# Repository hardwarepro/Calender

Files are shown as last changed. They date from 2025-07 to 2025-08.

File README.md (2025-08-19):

# Calender
This is a custom-built calender PCB that allows me to upload my school schedule (or just counting down how many days of school I have left!) via WIFI (on an esp32) to an e-ink display and use it in my locker off a AA battery. When it's at home, it will be able to act as a music player or still a calender, allowing me to plug it in via usb-c or just by using wifi and display live music status.  

## Photos






## BOM

| Name | Part # | JLCPCB Part # | Qty | Total Price |
| :--- | :--- | :--- | :--- | :--- |
| 10uF | CL10A106KP8NNNC | C19702 | 20 | 0.112 |
| 4.7uF | CL10A475KO8NNNC | C19666 | 20 | 0.202 |
| 1uF | CL10A105KB8NNNC | C15849 | 20 | 0.094 |
| 100nF | CC0603KRX7R9BB104 | C14663 | 22 | 0.0506 |
| Conn_01x09 | ZX-PZ1.0-1-9PZZ | C37328859 | 2 | 0.2856 |
| USB_C_Receptacle_USB2.0_16P | GT-USB-7010ASV | C2988369 | 2 | 0.1572 |
| Power | DB128L-5.08-2P-GN-S | C395868 | 2 | 0.3622 |
| 5.1k | 0603WAF5101T5E | C23186 | 20 | 0.02 |
| 2k | 0603WAF2001T5E | C22975 | 20 | 0.02 |
| 10k | 0603WAF1002T5E | C25804 | 26 | 0.0234 |
| 100kΩ | 0603WAF1003T5E | C25803 | 20 | 0.02 |
| RotaryEncoder_Switch | EC11E18244AU | C202365 | 2 | 3.825 |
| SW_Push | BTSA-N-P-13 | C2693637 | 0 | 0 |
| ATSAMD21G18A-A | ATSAMD21G18A-AU | C78624 | 2 | 6.249 |
| MCP73871 | MCP73871T-2CCI/ML | C511310 | 2 | 7.482 |
| ESP-WROOM-02 | ESP-WROOM-02D-N4 | C529584 | 2 | 3.75 |
| AMS1117-3.3V | AMS1117-3.3V |  | 2 | 1.25 |
| PCB | | | $76.80 after tax + shipping ||

---

## Other Items

| Item | Details/Source | Qty | Price |
| :--- | :--- | :--- | :--- |
| 0.91 OLED | 0.91 OLED | 1 | $1.15 since mine just broke :( |
| E-Ink Display | [From Waveshare](https://www.waveshare.com/3.7inch-e-paper-hat-plus-g.htm?sku=31061) | 2 | $48.98 after tax + shipping |

---

### **TOTAL: $126.93 USD without customs**

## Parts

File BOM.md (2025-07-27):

| Name | Part # | JLCPCB Part # | Qty | Total Price |
| :--- | :--- | :--- | :--- | :--- |
| 10uF | CL10A106KP8NNNC | C19702 | 20 | 0.112 |
| 4.7uF | CL10A475KO8NNNC | C19666 | 20 | 0.202 |
| 1uF | CL10A105KB8NNNC | C15849 | 20 | 0.094 |
| 100nF | CC0603KRX7R9BB104 | C14663 | 22 | 0.0506 |
| Conn_01x09 | ZX-PZ1.0-1-9PZZ | C37328859 | 2 | 0.2856 |
| USB_C_Receptacle_USB2.0_16P | GT-USB-7010ASV | C2988369 | 2 | 0.1572 |
| Power | DB128L-5.08-2P-GN-S | C395868 | 2 | 0.3622 |
| 5.1k | 0603WAF5101T5E | C23186 | 20 | 0.02 |
| 2k | 0603WAF2001T5E | C22975 | 20 | 0.02 |
| 10k | 0603WAF1002T5E | C25804 | 26 | 0.0234 |
| 100kΩ | 0603WAF1003T5E | C25803 | 20 | 0.02 |
| RotaryEncoder_Switch | EC11E18244AU | C202365 | 2 | 3.825 |
| SW_Push | BTSA-N-P-13 | C2693637 | 0 | 0 |
| ATSAMD21G18A-A | ATSAMD21G18A-AU | C78624 | 2 | 6.249 |
| MCP73871 | MCP73871T-2CCI/ML | C511310 | 2 | 7.482 |
| ESP-WROOM-02 | ESP-WROOM-02D-N4 | C529584 | 2 | 3.75 |
| PCB | | | $71.70 after tax + shipping |

---

## Other Items

| Item | Details/Source | Qty | Price |
| :--- | :--- | :--- | :--- |
| AMS1117-3.3V (So I don't need to do 2 layer assembly. I will just hand-solder this myself)| From Digikey | 1 | $6.96 after tax + shipping |
| E-Ink Display | [From Waveshare](https://www.waveshare.com/3.7inch-e-paper-hat-plus-g.htm?sku=31061) | 1 | $26.99 after tax + $5 shipping |

---

### **TOTAL: $110 USD without customs**

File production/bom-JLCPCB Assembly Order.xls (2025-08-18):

JLCPCB BOM Tool - BOM Matching
BOM name：bom-JLCPCB Assembly Order.xlsx |  |  | Download Time：2025-08-19 04:42:18 |  |  |  | * Our matching results are updated in real-time, but stock and prices may change. If it's been over 24 hours, please re-match before placing your order.
PCB Assembled Qty：5 |  |  | Est. Total Price：26.9299
Your BOM |  |  |  |  | Matched Parts |  |  |  |  |  |  | Order Information
Top Designator | Bottom Designator | Comment | Footprint | JLCPCB Part # | Matches | Part # | Manufacturer | Footprint | Description | Category | Warning | JLCPCB Part # | Product link | Lib Type | Qty | Source | Total Price ($)
C1,C2 |  | 10uF | 0603 |  | Select by System | CL10A106KP8NNNC | Samsung Electro-Mechanics | 0603 | 10V 10uF X5R ±10% 0603 Multilayer Ceramic Capacitors MLCC - SMD/SMT ROHS | Multilayer Ceramic Capacitors MLCC - SMD/SMT |  | C19702 | https://jlcpcb.com/partdetail/20411-CL10A106KP8NNNC/C19702 | Basic | 4 | 4 JLCPCB | 0.0224
C3,C4 |  | 4.7uF | 0603 |  | Select by System | CL10A475KO8NNNC | Samsung Electro-Mechanics | 0603 | 16V 4.7uF X5R ±10% 0603 Multilayer Ceramic Capacitors MLCC - SMD/SMT ROHS | Multilayer Ceramic Capacitors MLCC - SMD/SMT |  | C19666 | https://jlcpcb.com/partdetail/20375-CL10A475KO8NNNC/C19666 | Basic | 4 | 4 JLCPCB | 0.0404
C5 |  | 1uF | 0603 |  | Select by System | CL10A105KB8NNNC | Samsung Electro-Mechanics | 0603 | 1uF 50V X5R ±10% 0603 Multilayer Ceramic Capacitors MLCC - SMD/SMT ROHS | Multilayer Ceramic Capacitors MLCC - SMD/SMT |  | C15849 | https://jlcpcb.com/partdetail/16531-CL10A105KB8NNNC/C15849 | Basic | 2 | 2 JLCPCB | 0.0094
C10,C11,C12,C6,C7,C8,C9 |  | 100nF | 0603 |  | Select by System | CC0603KRX7R9BB104 | YAGEO | 0603 | 100nF 50V X7R ±10% 0603 Multilayer Ceramic Capacitors MLCC - SMD/SMT ROHS | Multilayer Ceramic Capacitors MLCC - SMD/SMT |  | C14663 | https://jlcpcb.com/partdetail/YAGEO-CC0603KRX7R9BB104/C14663 | Basic | 14 | 14 JLCPCB | 0.0322
J1 |  | Conn_01x09 | PinHeader_1x09_P1.00mm_Vertical |  | Select by Customer | ZX-PZ1.0-1-9PZZ | Megastar | 插件,P=1mm | -40℃~+105℃ 1 1mm 1mm 1x9P 2mm 2mm 750mA 9P Black Brass Gold Pin Header Through Hole Plugin,P=1mm Pin Headers ROHS | Pin Headers |  | C37328859 | https://jlcpcb.com/partdetail/Megastar-ZX_PZ1_0_19PZZ/C37328859 | Extended | 2 | 2 JLCPCB | 0.2862
J2 |  | USB_C_Receptacle_USB2.0_16P | USB_C_Receptacle_HCTL_HC-TYPE-C-16P-01A |  | Select by Customer | GT-USB-7010AN | G-Switch | SMD | -40℃~+85℃ 1 1.68mm 10,000 Cycles 16P 24V 5A 7.35mm Black Female Surface Mount, Right Angle Type-C USB 2.0 SMD USB Connectors ROHS | USB Connectors |  | C963370 | https://jlcpcb.com/partdetail/GSwitch-GT_USB7010AN/C963370 | Extended | 5 | 5 JLCPCB | 0.9445
J3 |  | Power | TerminalBlock_bornier-2_P5.08mm |  | Select by Customer | WJ500V-5.08-2P | Ningbo Kangnex Elec | 插件,P=5.08mm | -40℃~+105℃ 1 14~30 18A 1x2P 2 2.5 250V 2P 5.08mm Green M2.5 Through Hole Plugin,P=5.08mm Screw Terminal Blocks ROHS | Screw Terminal Blocks | 1.The comment (WJ500V-5.08-2P) of this part does not match the one (Power) provided in your BOM. Please confirm; | C8465 | https://jlcpcb.com/partdetail/Ningbo_KangnexElec-WJ500V_5_082P/C8465 | Extended | 2 | 2 JLCPCB | 0.2128
J4 |  | Screen-2 | PinHeader_1x04_P2.54mm_Vertical |  | Select by Customer | PZ254V-11-04P | XFCN | 插件,P=2.54mm | -40℃~+105℃ 1 1x4P 2.54mm 2.5mm 250V 3A 3mm 4P 6mm Black Pin Header Through Hole Plugin,P=2.54mm Pin Headers ROHS | Pin Headers |  | C2691448 | https://jlcpcb.com/partdetail/XFCN-PZ254V_1104P/C2691448 | Extended | 3 | 3 JLCPCB | 0.0621
R1,R2,R4 |  | 5.1k | 0603 |  | Unconfirmed | 0603WAF5101T5E | UNI-ROYAL(Uniroyal Elec) | 0603 | -55℃~+155℃ 100mW 5.1kΩ 75V Thick Film Resistor ±1% ±100ppm/℃ 0603 Chip Resistor - Surface Mount ROHS | Chip Resistor - Surface Mount | 1.The comment (0603WAF5101T5E) of this part does not match the one (5.1k) provided in your BOM. Please confirm; | C23186 | https://jlcpcb.com/partdetail/23913-0603WAF5101T5E/C23186 | Basic | 6 | 6 JLCPCB | 0.006
R5 |  | 2k | 0603 |  | Unconfirmed | 0603WAF2001T5E | UNI-ROYAL(Uniroyal Elec) | 0603 | -55℃~+155℃ 100mW 2kΩ 75V Thick Film Resistor ±1% ±100ppm/℃ 0603 Chip Resistor - Surface Mount ROHS | Chip Resistor - Surface Mount | 1.The comment (0603WAF2001T5E) of this part does not match the one (2k) provided in your BOM. Please confirm; | C22975 | https://jlcpcb.com/partdetail/23702-0603WAF2001T5E/C22975 | Basic | 2 | 2 JLCPCB | 0.002
R10,R12,R13,R14,R19,R3,R6,R7,R8,R9 |  | 10k | 0603 |  | Unconfirmed | 0603WAF1002T5E | UNI-ROYAL(Uniroyal Elec) | 0603 | -55℃~+155℃ 100mW 10kΩ 75V Thick Film Resistor ±1% ±100ppm/℃ 0603 Chip Resistor - Surface Mount ROHS | Chip Resistor - Surface Mount | 1.The comment (0603WAF1002T5E) of this part does not match the one (10k) provided in your BOM. Please confirm; 2.Multiple lines in the BOM have been matched to the same part. Please check if the matching is correct. ; | C25804 | https://jlcpcb.com/partdetail/26547-0603WAF1002T5E/C25804 | Basic | 26 | 26 JLCPCB | 0.0234
R16,R17,R18 |  | 10kΩ | 0603 |  | Unconfirmed | 0603WAF1002T5E | UNI-ROYAL(Uniroyal Elec) | 0603 | -55℃~+155℃ 100mW 10kΩ 75V Thick Film Resistor ±1% ±100ppm/℃ 0603 Chip Resistor - Surface Mount ROHS | Chip Resistor - Surface Mount | 1.Multiple lines in the BOM have been matched to the same part. Please check if the matching is correct. ; | C25804 | https://jlcpcb.com/partdetail/26547-0603WAF1002T5E/C25804 | Basic | 26 | 26 JLCPCB | 0.0234
R11 |  | 100kΩ | 0603 |  | Select by System | 0603WAF1003T5E | UNI-ROYAL(Uniroyal Elec) | 0603 | -55℃~+155℃ 100kΩ 100mW 75V Thick Film Resistor ±1% ±100ppm/℃ 0603 Chip Resistor - Surface Mount ROHS | Chip Resistor - Surface Mount |  | C25803 | https://jlcpcb.com/partdetail/26546-0603WAF1003T5E/C25803 | Basic | 2 | 2 JLCPCB | 0.002
R15 |  | 1.5k | 0603 |  | Unconfirmed | 0603WAF1501T5E | UNI-ROYAL(Uniroyal Elec) | 0603 | -55℃~+155℃ 1.5kΩ 100mW 75V Thick Film Resistor ±1% ±100ppm/℃ 0603 Chip Resistor - Surface Mount ROHS | Chip Resistor - Surface Mount | 1.The comment (0603WAF1501T5E) of this part does not match the one (1.5k) provided in your BOM. Please confirm; | C22843 | https://jlcpcb.com/partdetail/23570-0603WAF1501T5E/C22843 | Basic | 2 | 2 JLCPCB | 0.002
SW1 |  | RotaryEncoder_Switch | RotaryEncoder_Alps_EC11E-Switch_Vertical_H20mm |  | Select by Customer | EC11E15244B2 | ALPSALPINE | 插件 | Plugin Rotary Encoders ROHS | Rotary Encoders |  | C470754 | https://jlcpcb.com/partdetail/ALPSALPINE-EC11E15244B2/C470754 | Extended | 2 | 2 JLCPCB | 3.891
SW2,SW3,SW4 |  | SW_Push | SW_PUSH_6mm |  | Select by Customer | TS-1002S-05026C | XUNPU | SMD,6x6mm | 12V 50mA 5mm 6mm 6mm Round Button SPST Surface Mount,Vertical SMD,6x6mm Tactile Switches ROHS | Tactile Switches |  | C455110 | https://jlcpcb.com/partdetail/XUNPU-TS_1002S05026C/C455110 | Extended | 7 | 7 JLCPCB | 0.2975
U1 |  | ATSAMD21G18A-A | TQFP-48_7x7mm_P0.5mm |  | Select by System | ATSAMD21G18A-AU | Microchip Tech | TQFP-48(7x7) | 1.62V~3.63V 10bit 12bit 256KB 48 48MHz ARM Cortex-M Series FLASH TQFP-48(7x7) Microcontrollers (MCU/MPU/SOC) ROHS | Microcontrollers (MCU/MPU/SOC) |  | C78624 | https://jlcpcb.com/partdetail/MicrochipTech-ATSAMD21G18AAU/C78624 | Extended | 2 | 2 JLCPCB | 6.249
U3 |  | MCP73871 | QFN-20-1EP_4x4mm_P0.5mm_EP2.5x2.5mm |  | Select by System | MCP73871T-2CCI/ML | Microchip Tech | QFN-20-EP(4x4) | -40℃~+85℃ 1 4.2V 4.6V~6V Lithium-ion/Polymer QFN-20-EP(4x4) Battery Management ROHS | Battery Management |  | C511310 | https://jlcpcb.com/partdetail/MicrochipTech-MCP73871T_2CCIML/C511310 | Extended | 2 | 2 JLCPCB | 7.938
U4 |  | AMS1117-3.3 | SOT-223-3_TabPin2 |  | Select by System | AMS1117-3.3 | Advanced Monolithic Systems | SOT-223 | -40℃~+125℃ 1 1.1V@(800mA) 16V 1A 3.3V 5mA 72dB@(120Hz) Fixed Over Current Protection Positive SOT-223 Voltage Regulators - Linear, Low Drop Out (LDO) Regulators ROHS | Voltage Regulators - Linear, Low Drop Out (LDO) Regulators |  | C6186 | https://jlcpcb.com/partdetail/Advanced_MonolithicSystems-AMS1117_33/C6186 | Basic | 2 | 2 JLCPCB | 0.3306
U5 |  | ESP-WROOM-02 | ESP-WROOM-02 |  | Unconfirmed | ESP-WROOM-02D-N4 | Espressif Systems | SMD,18x20mm | SMD,18x20mm WiFi Modules ROHS | WiFi Modules | 1.The comment (ESP-WROOM-02D-N4) of this part does not match the one (ESP-WROOM-02) provided in your BOM. Please confirm; | C529584 | https://jlcpcb.com/partdetail/EspressifSystems-ESP_WROOM_02DN4/C529584 | Extended | 2 | 2 JLCPCB | 3.75
U6 |  | NAND | SOIC-8_5.3x5.3mm_P1.27mm |  | Select by Customer | ZD25Q256ASIGT | Zetta | SOP-8-208mil | 100,000 Cycles 100MHz 2.7V~3.6V 20 Years 256Mbit 5uA SPI SOP-8-208mil NOR FLASH ROHS | NOR FLASH |  | C41364479 | https://jlcpcb.com/partdetail/Zetta-ZD25Q256ASIGT/C41364479 | Extended | 2 | 2 JLCPCB | 2.805

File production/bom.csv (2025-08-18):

Designator | Footprint | Quantity | Value | LCSC Part #
C1, C2 | 0603 | 2 | 10uF
C10, C11, C12, C6, C7, C8, C9 | 0603 | 7 | 100nF
C3, C4 | 0603 | 2 | 4.7uF
C5 | 0603 | 1 | 1uF
J1 | PinHeader_1x09_P1.00mm_Vertical | 1 | Conn_01x09
J2 | USB_C_Receptacle_HCTL_HC-TYPE-C-16P-01A | 1 | USB_C_Receptacle_USB2.0_16P
J3 | TerminalBlock_bornier-2_P5.08mm | 1 | Power
J4 | PinHeader_1x04_P2.54mm_Vertical | 1 | Screen-2
R1, R2, R4 | 0603 | 3 | 5.1k
R10, R12, R13, R14, R19, R3, R6, R7, R8, R9 | 0603 | 10 | 10k
R11 | 0603 | 1 | 100kΩ
R15 | 0603 | 1 | 1.5k
R16, R17, R18 | 0603 | 3 | 10kΩ
R5 | 0603 | 1 | 2k
SW1 | RotaryEncoder_Alps_EC11E-Switch_Vertical_H20mm | 1 | RotaryEncoder_Switch
SW2, SW3, SW4 | SW_PUSH_6mm | 3 | SW_Push
TP1, TP2, TP3, TP4, TP5, TP8 | TestPoint_Pad_4.0x4.0mm | 6 | TestPoint
U1 | TQFP-48_7x7mm_P0.5mm | 1 | ATSAMD21G18A-A
U3 | QFN-20-1EP_4x4mm_P0.5mm_EP2.5x2.5mm | 1 | MCP73871
U4 | SOT-223-3_TabPin2 | 1 | AMS1117-3.3
U5 | ESP-WROOM-02 | 1 | ESP-WROOM-02
U6 | SOIC-8_5.3x5.3mm_P1.27mm | 1 | NAND

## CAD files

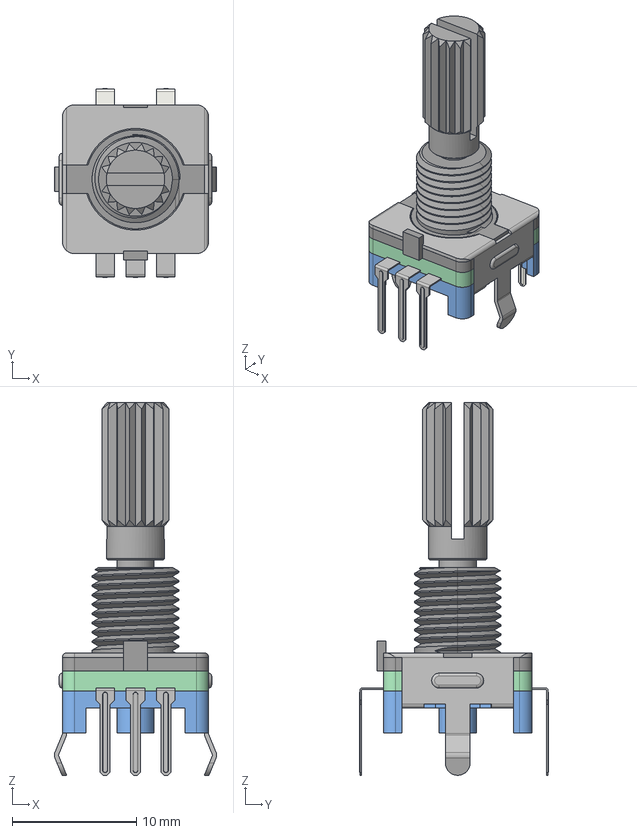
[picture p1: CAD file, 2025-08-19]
EC11_Rotary_Encoder_Switched.step
13.1 x 15.3 x 30.1 mm

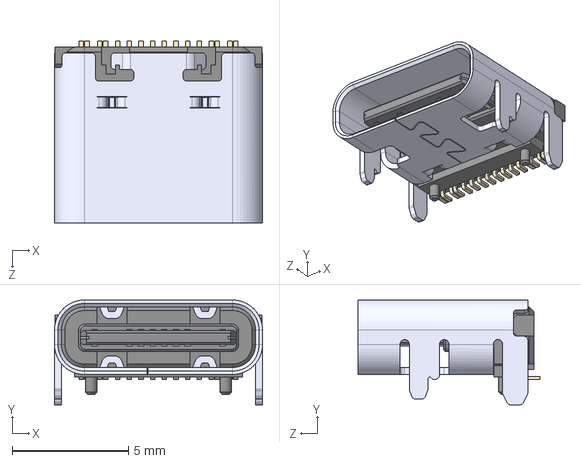
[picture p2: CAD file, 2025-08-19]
KH-TYPE-C-16P--3DModel-STEP-269445.STEP
8.94 x 4.51 x 7.81 mm

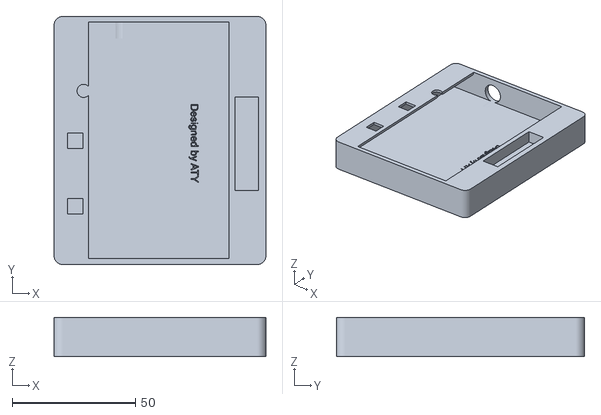
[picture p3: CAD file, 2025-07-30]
case.stl
86.0 x 100.7 x 16.0

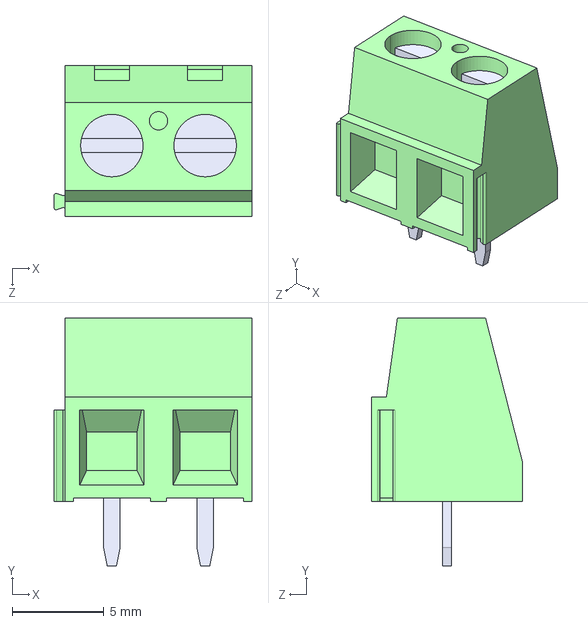
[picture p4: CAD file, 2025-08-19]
282837-2--3DModel-STEP-269445.STEP
10.8 x 13.5 x 8.20 mm

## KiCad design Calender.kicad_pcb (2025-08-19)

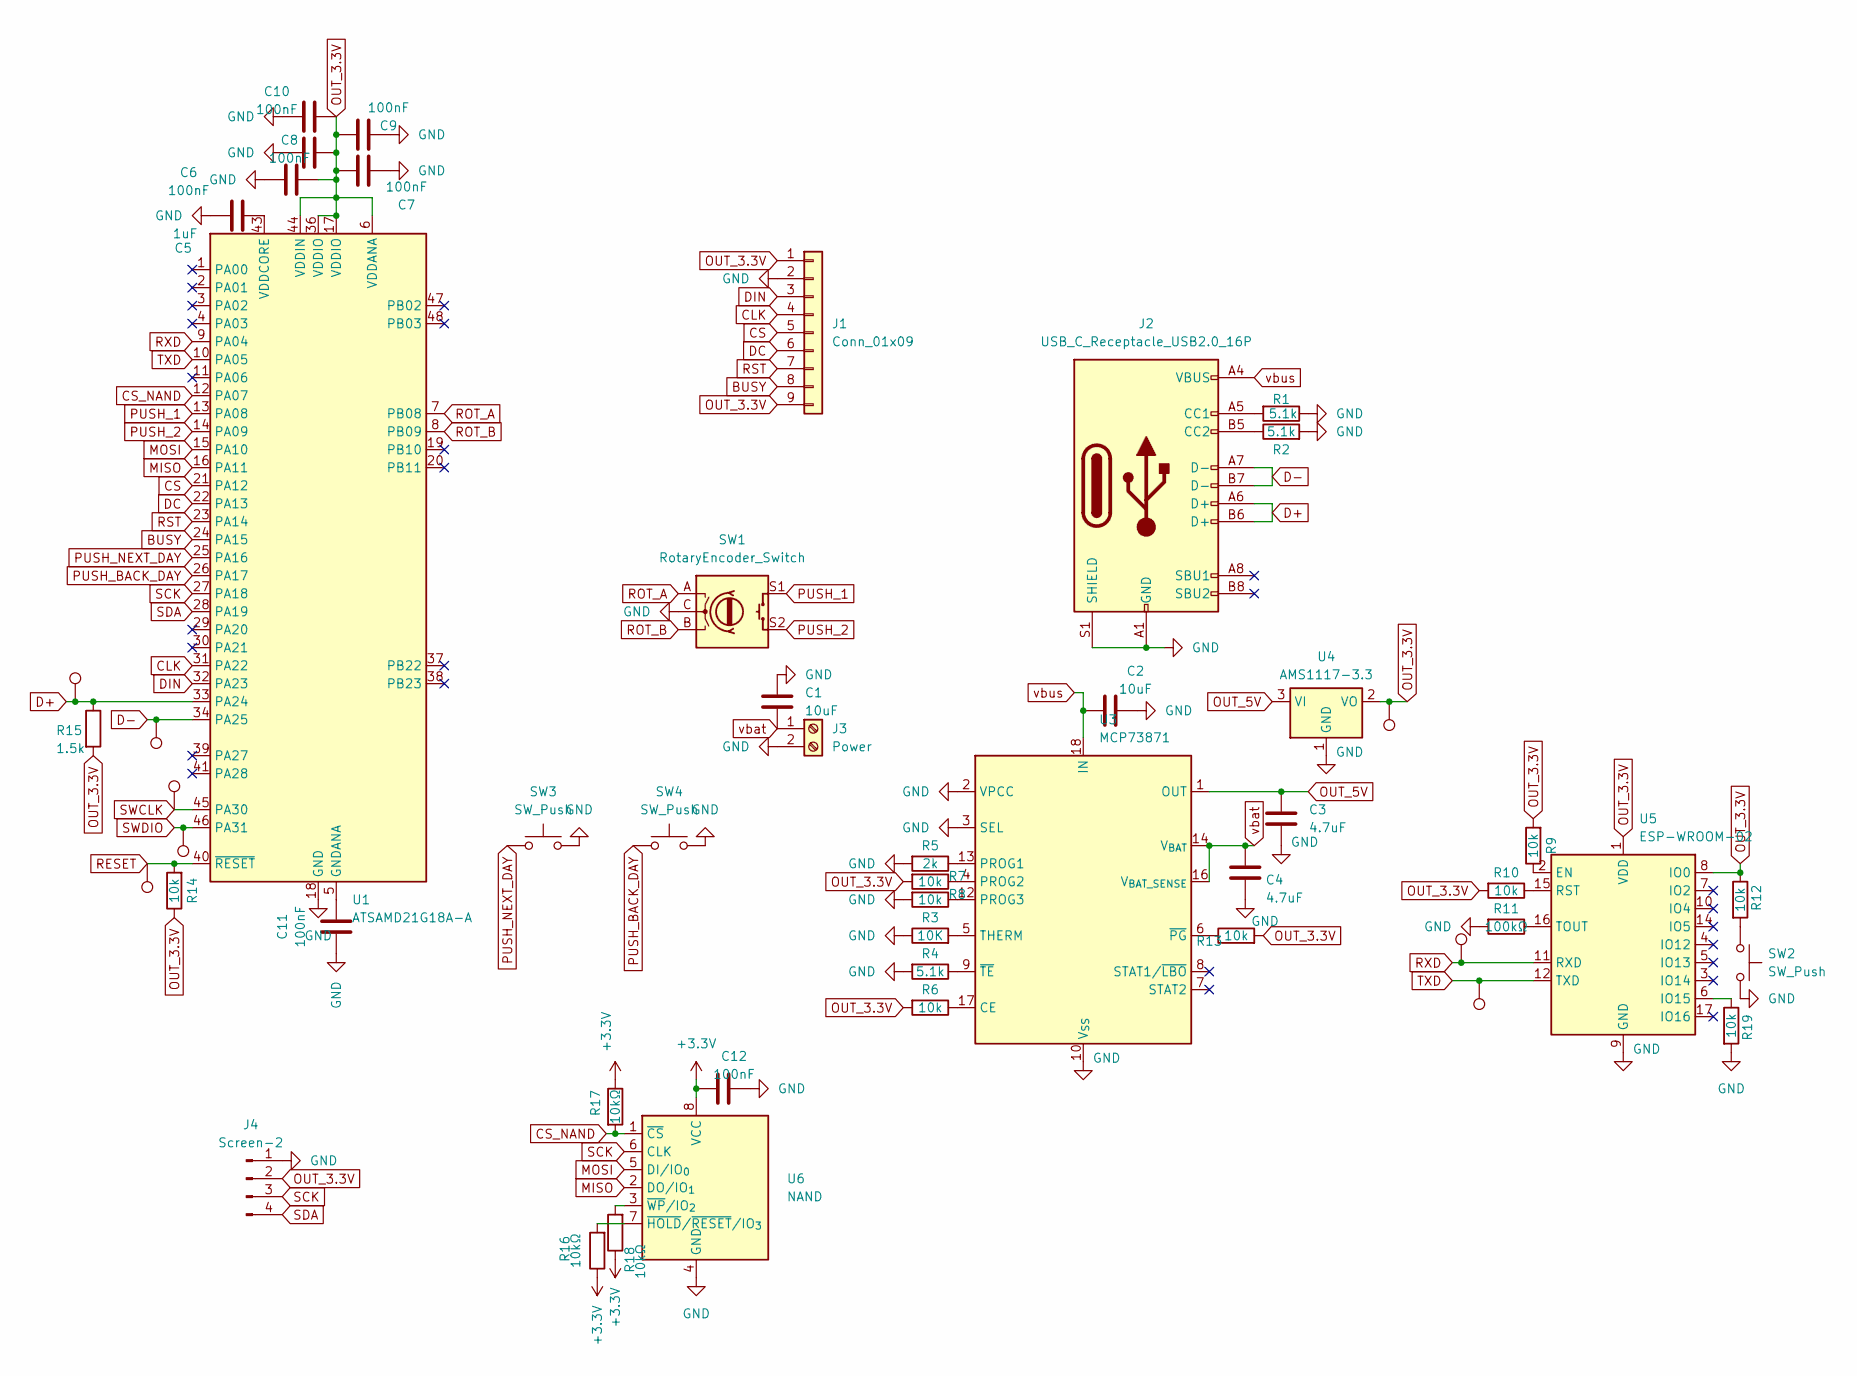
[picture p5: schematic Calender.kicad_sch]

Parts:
C1, C2: 10uF; C_0603_1608Metric
C3, C4: 4.7uF; C_0603_1608Metric
C5: 1uF; C_0603_1608Metric
C6, C7, C8, C9, C10, C11, C12: 100nF; C_0603_1608Metric
J1: Conn_01x09; PinHeader_1x09_P1.00mm_Vertical
J2: USB_C_Receptacle_USB2.0_16P; USB_C_Receptacle_HCTL_HC-TYPE-C-16P-01A
J3: Power; TerminalBlock_bornier-2_P5.08mm
J4: Screen-2; PinHeader_1x04_P2.54mm_Vertical
R1, R2, R4: 5.1k; R_0603_1608Metric
R3: 10K; R_0603_1608Metric
R5: 2k; R_0603_1608Metric
R6, R7, R8, R9, R10, R12, R13, R14, R19: 10k; R_0603_1608Metric
R11: 100kΩ; R_0603_1608Metric
R15: 1.5k; R_0603_1608Metric
R16, R17, R18: 10kΩ; R_0603_1608Metric
SW1: RotaryEncoder_Switch; RotaryEncoder_Alps_EC11E-Switch_Vertical_H20mm
SW2, SW3, SW4: SW_Push; SW_PUSH_6mm
TP1, TP2, TP3, TP4, TP5, TP6, TP7, TP8: TestPoint; Pin_D1.0mm_L10.0mm_LooseFit
U1: ATSAMD21G18A-A; TQFP-48_7x7mm_P0.5mm
U3: MCP73871; QFN-20-1EP_4x4mm_P0.5mm_EP2.5x2.5mm
U4: AMS1117-3.3; SOT-223-3_TabPin2
U5: ESP-WROOM-02
U6: NAND; SOIC-8_5.3x5.3mm_P1.27mm

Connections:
+3.3V: C12.1, R16.1, R17.1, R18.1, U6.8 (VCC)
BUSY: J1.8, U1.24 (PA15)
CLK: J1.4, U1.31 (PA22)
CS: J1.5, U1.21 (PA12)
CS_NAND: R17.2, U1.12 (PA07), U6.1 (~CS)
D+: J2.A6 (D+), J2.B6 (D+), R15.1, TP6.1, U1.33 (PA24)
D-: J2.A7 (D-), J2.B7 (D-), TP7.1, U1.34 (PA25)
DC: J1.6, U1.22 (PA13)
DIN: J1.3, U1.32 (PA23)
GND: C1.1, C2.2, C3.2, C4.2, C5.2, C6.2, C7.2, C8.2, C9.2, C10.2, C11.2, C12.2, J1.2, J2.A1 (GND), J2.A12 (GND), J2.B1 (GND), J2.B12 (GND), J2.S1 (SHIELD), J3.2, J4.1, R1.1, R2.2, R3.1, R4.2, R5.2, R8.2, R11.2, R19.2, SW1.C, SW2.2, SW3.2, SW4.2, U1.18 (GND), U1.35 (GND), U1.42 (GND), U3.2 (VPCC), U3.3 (SEL), U3.10 (V_{SS}), U3.11 (V_{SS}), U3.21 (V_{SS}), U4.1 (GND), U5.9 (GND), U5.13 (GND), U5.18 (GND), U5.19 (GND), U6.4 (GND)
MISO: U1.16 (PA11), U6.2 (DO/IO_{1})
MOSI: U1.15 (PA10), U6.5 (DI/IO_{0})
unnamed: J2.A5 (CC1), R1.2
unnamed: J2.B5 (CC2), R2.1
unnamed: R12.2, SW2.1
unnamed: C11.1, U1.5 (GNDANA)
unnamed: C5.1, U1.43 (VDDCORE)
unnamed: R6.1, U3.17 (CE)
unnamed: R5.1, U3.13 (PROG1)
unnamed: R7.1, U3.4 (PROG2)
unnamed: R8.1, U3.12 (PROG3)
unnamed: R3.2, U3.5 (THERM)
unnamed: R13.1, U3.6 (~PG)
unnamed: R4.1, U3.9 (~TE)
unnamed: R9.1, U5.2 (EN)
unnamed: R19.1, U5.6 (IO15)
unnamed: R10.1, U5.15 (RST)
unnamed: R11.1, U5.16 (TOUT)
unnamed: R16.2, U6.7 (~HOLD/~RESET/IO_{3})
unnamed: R18.2, U6.3 (~WP/IO_{2})
OUT_3.3V: C6.1, C7.1, C8.1, C9.1, C10.1, J1.1, J1.9, J4.2, R6.2, R7.2, R9.2, R10.2, R12.1, R13.2, R14.1, R15.2, TP8.1, U1.6 (VDDANA), U1.17 (VDDIO), U1.36 (VDDIO), U1.44 (VDDIN), U4.2 (VO), U5.1 (VDD), U5.8 (IO0)
OUT_5V: C3.1, U3.1 (OUT), U3.20 (OUT), U4.3 (VI)
PUSH_1: SW1.S1, U1.13 (PA08)
PUSH_2: SW1.S2, U1.14 (PA09)
PUSH_BACK_DAY: SW4.1, U1.26 (PA17)
PUSH_NEXT_DAY: SW3.1, U1.25 (PA16)
RESET: R14.2, TP3.1, U1.40 (~RESET)
ROT_A: SW1.A, U1.7 (PB08)
ROT_B: SW1.B, U1.8 (PB09)
RST: J1.7, U1.23 (PA14)
RXD: TP2.1, U1.9 (PA04), U5.11 (RXD)
SCK: J4.3, U1.27 (PA18), U6.6 (CLK)
SDA: J4.4, U1.28 (PA19)
SWCLK: TP5.1, U1.45 (PA30)
SWDIO: TP4.1, U1.46 (PA31)
TXD: TP1.1, U1.10 (PA05), U5.12 (TXD)
vbat: C1.2, C4.1, J3.1, U3.14 (V_{BAT}), U3.15 (V_{BAT}), U3.16 (V_{BAT_SENSE})
vbus: C2.1, J2.A4 (VBUS), J2.A9 (VBUS), J2.B4 (VBUS), J2.B9 (VBUS), U3.18 (IN), U3.19 (IN)

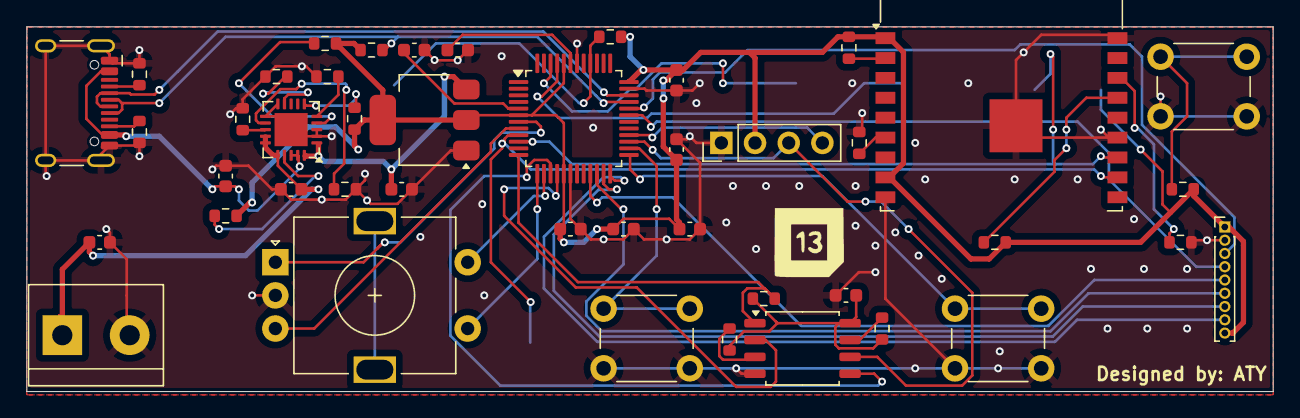
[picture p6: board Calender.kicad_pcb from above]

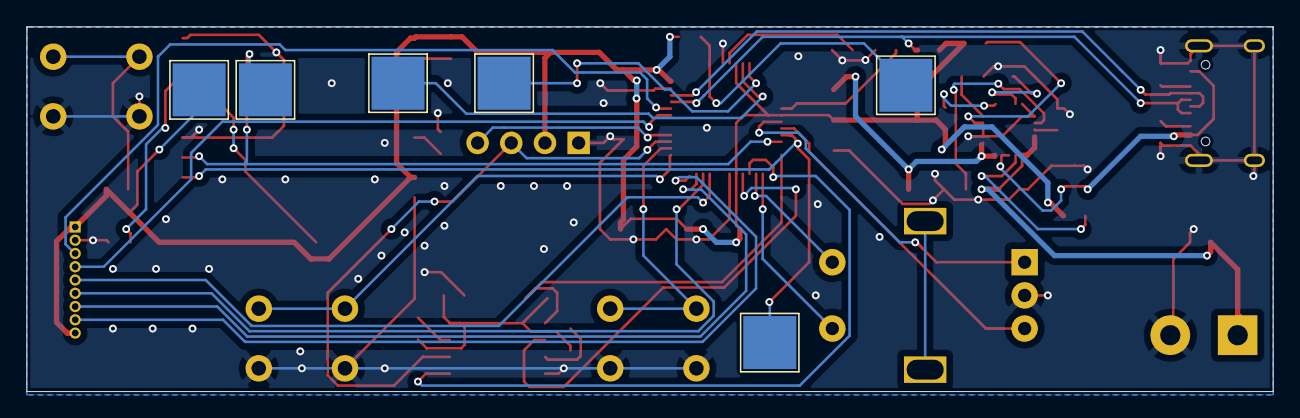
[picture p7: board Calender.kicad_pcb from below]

Board: 2 copper layers, 94.0 x 27.5 mm, 50 parts (6 on the bottom side), 48 nets.

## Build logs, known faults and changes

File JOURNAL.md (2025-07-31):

**Project** - This is a custom-built calender PCB that allows me to upload my school schedule (or just counting down how many days of school I have left!) via WIFI (on an esp32) to an e-ink display and use it in my locker off a AA battery. When it's at home, it will be able to act as a music player or still a calender, allowing me to plug it in via usb-c or just by using wifi and display live music status.

**Total time spent** - 16 hours

## Day 1 - June 25th- 7 hours
This is the first day I started working on it. I can up with the idea beacuse I use to count down the days of school and mark my calendar on a white board, but with this I will be able to keep it all synced up, and displayed nicely. I started off with doing the schematic. My brother told me to use the SAMD21G18A as it is a nice MCU, and I chose the ESP32 for the wifi ascpect of it. I decided I also wanted an e-ink display as it has maximum power saving and looks cool, so I chose the https://www.waveshare.com/3.7inch-e-paper-hat-plus-g.htm?sku=31061.
Switching from the battery to the USB power was very difficult as I didn't know what chips to use, and the schematic for them seemed hard. With a lot of reading, and a little help, I think I got the schematic all finished up for that ascpect, and overall too. It has one USB-C, a SAMD21G18A-AU, a ESP32, 2 buttons, a rotary encoder, and battery to usb power switching, along with the headers for my display.

## Day 2 - July 8th - 5.5 hours
Today was my first day of routing this PCB. Along with this being the hardest PCB I've routed, it was also only my 2nd one ever, so I was worried something would go wrong. After my brother gave me some optimal spots to place the parts, I started routing it all by myself. I started off with the power, like the battery and stuff, and moved on to wiring the USB lines. Once that was done, I started wiring the power switching stuff. It was definitly hard, especially trying to put everything on only one layer, but after some time I got it. Lastly, everything got routed to the SAMD21, and I called it done for today. I pretty much routed everything to the board.
That whole essay above pretty much sums up 5.5 hours of figuring out the best way to route it with a lot of trial and error. Along the way, I learnt some cool stuff like you can have vias right under parts and what ground pours are.


## Day 3 - July 27th - 2 hours
After totally not forgetting that I needed to submit it, I got back to it, and looked it over with my brother for the final time to make sure everything was good. I found a small error were I needed a pullup resistor on D+ for it to functional properly. Besides for that, there were a few small errors on my PCB, and some routing lines that looked ugly, so I fixed that up. I also added my silkscreen today which is the Google Calender logo, but it's in the copper layer so it looks pretty cool.


## Day 4 - July 30th - 1.5 hours

Today, I pretty much fixed up everything that was requested for this board to be approved. I started off with fixing the PCB. There were some caps that we so far from there main IC, so I moved it closer. I also moved the voltage converter and one cap to the front side of the board so JLCPCB could assemble all the parts, and not make it hand-solder 2 of them. Next I made my case. I totally forgot about designing the case. Since I'm not a crazy CAD user, I started off with getting a rough idea of how I wanted it to be in tinkercad. Then, I was able to import my design in Fusion 360, and get exact measurements from there to make the case the right size for my board. It's a very simple case with some cutouts for the screen, EC11, the 2 buttons and the USB-C, but it works. I also learnt how to add a fillet to the sides to make everything rounded and cool!




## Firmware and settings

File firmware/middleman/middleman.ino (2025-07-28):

#include <WiFi.h>
#include <HTTPClient.h>
#include <ArduinoJson.h>

const char* ssid     = "NO LEEKS";
const char* password = "NO LEEKS";

const char* scheduleURL = "http://pi.local/schedule.json";

void setup() {
  Serial1.begin(115200, SERIAL_8N1, /*RX*/ 9, /*TX*/ 10); 

  WiFi.begin(ssid, password);
  while (WiFi.status() != WL_CONNECTED) {
    delay(500);
    Serial.print(".");
  }
  Serial.println("\nWiFi connected!");
}

void loop() {
  if (WiFi.status() == WL_CONNECTED) {
    HTTPClient http;
    http.begin(scheduleURL);
    int code = http.GET();
    if (code == 200) {
      String payload = http.getString();
      Serial1.println(payload);
      Serial.println("The schedule sent to the mcu.");
    } else {
      Serial.printf("Error!!!, code);
    }
    http.end();
  } else {
    Serial.println("Down!");
  }
  
  delay(60 * 60 * 1000UL);
}

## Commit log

2025-06-25 Finished the schematic
    [Calender.kicad_pcb, Calender.kicad_sch]
2025-07-08 all routing and stuff... definitely didn't forget to push
    [Calender.kicad_pcb, Calender.kicad_sch]
2025-07-08 Fixed via
    [Calender.kicad_pcb]
2025-07-08 PCB finished
    [Calender.kicad_pcb]
2025-07-09 Added BOM
2025-07-09 Added prod files and bootloader stuff
    [Calender.kicad_pcb, Calender.kicad_sch, bom.csv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]
2025-07-27 The PCB should be good now for production
    [Calender.kicad_pcb, Calender.kicad_sch, bom.csv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]
2025-07-29 Fixed PCB changes/errors
    [Calender.kicad_pcb, Calender.kicad_sch]
2025-07-30 Adding initial design for my case
    [case.stl]
2025-07-30 Fixed more small PCB changed. Everything should be good now.
    [Calender.kicad_pcb, bom.csv, designators.csv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]
2025-07-31 Added the pcb to the case
2025-08-18 have fun finishing the routing for it
    [Calender.kicad_pcb, Calender.kicad_sch]
2025-08-18 Should be finished
    [Calender.kicad_pcb, Calender.kicad_sch]
2025-08-18 Added production files
    [Calender.kicad_pcb, bom-JLCPCB Assembly Order.xls, bom.csv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]
2025-08-18 added folder
    [Calender-B_Cu.gbl, Calender-B_Mask.gbs, Calender-B_Paste.gbp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]
2025-08-19 added the newest 3d model
    [282837-2--3DModel-STEP-269445.STEP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]
